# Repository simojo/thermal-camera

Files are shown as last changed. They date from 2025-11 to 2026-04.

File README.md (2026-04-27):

# Thermal camera based on Raspberry Pi Pico and MLX90640

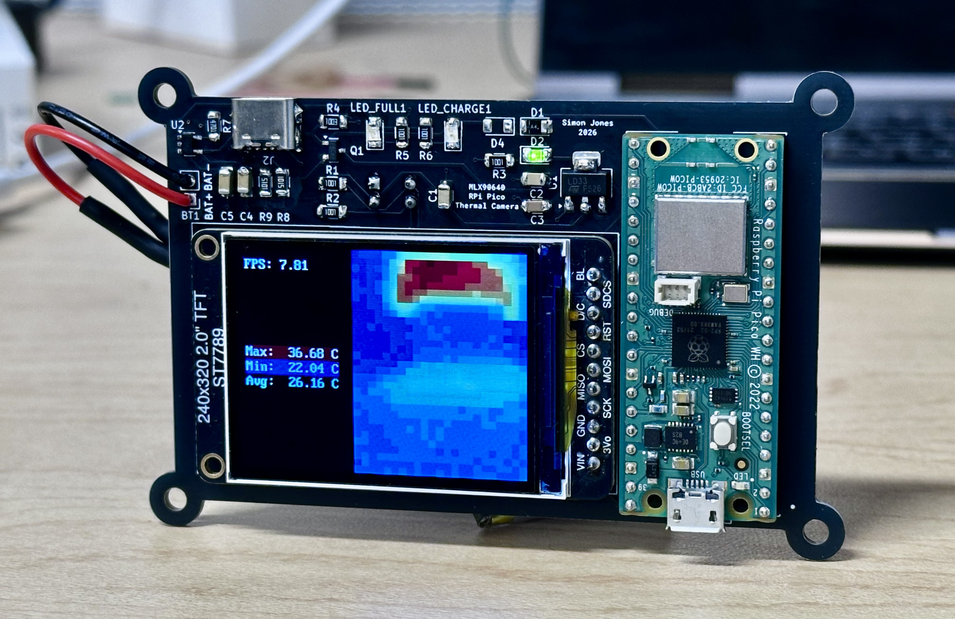
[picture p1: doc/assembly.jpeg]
Assembled Board


## Overview

This camera was a dream I've had for a while to use up some parts I had lying
around on my bench. I took an embedded system design course in Fall 2025 under
Linden McClure, and I used it as an opportunity to prototype a design using wire
wrapping. The code worked, and I could use it as a thermal camera, but in April
2026, I finally taped it out to a PCB which is conducive to an enclosure and
being more rugged. I wrote the library for displaying to the thin-film
transistor display manually as the key effort to the project.

## User features

* 7 FPS refresh rate
* Dynamic color mapping
* Real-time temperature readout (min/max)
* USB-C charging
* 3.7V Lithium polymer/ion battery

## Technical Features

* CMake based project
* KiCad based layout
* Supports charging over battery
* MCP73831 charger with charging/full indicators
* 3.3V logic and power

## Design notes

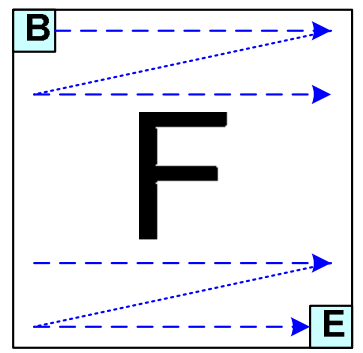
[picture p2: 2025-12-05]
st7789-orientation.png

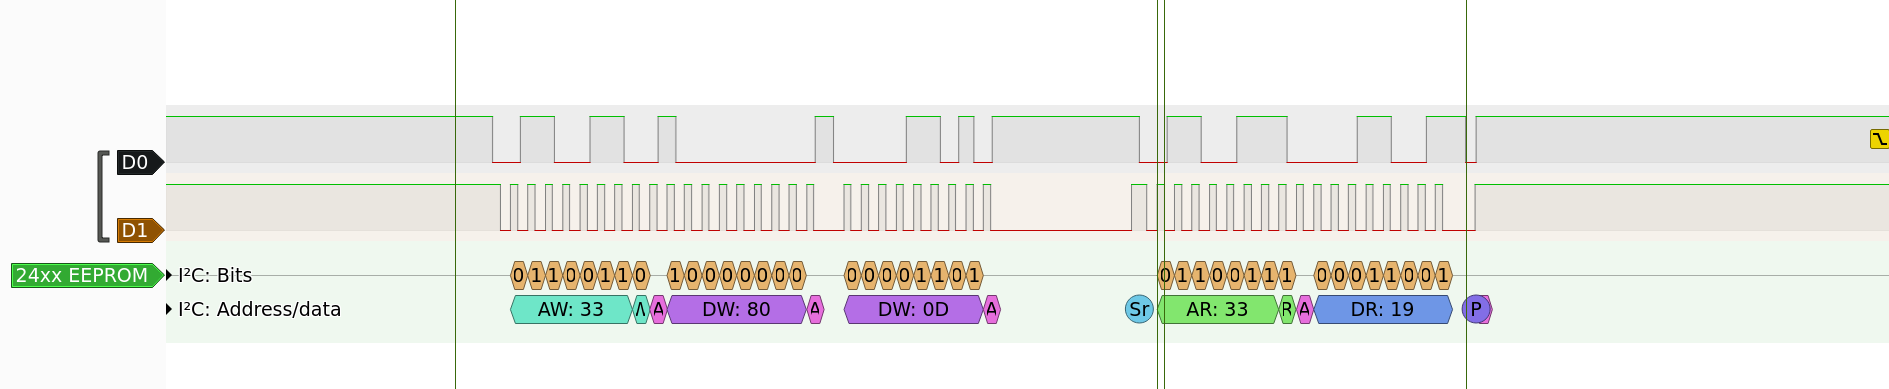
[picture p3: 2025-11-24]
first-logic-analyzer-reading.png

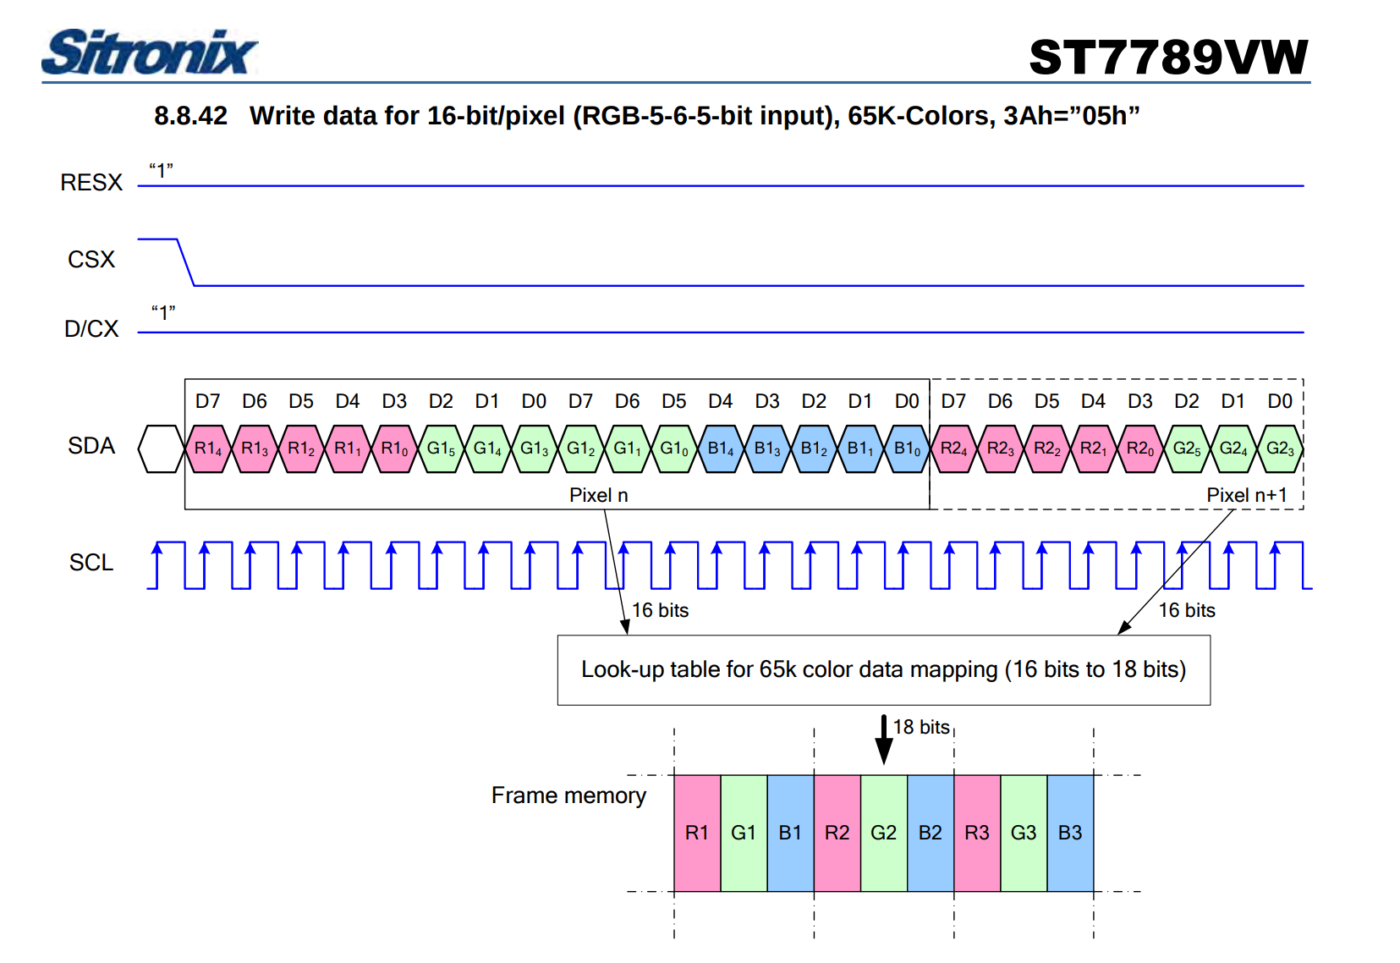
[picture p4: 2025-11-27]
rgb565-st7789.png

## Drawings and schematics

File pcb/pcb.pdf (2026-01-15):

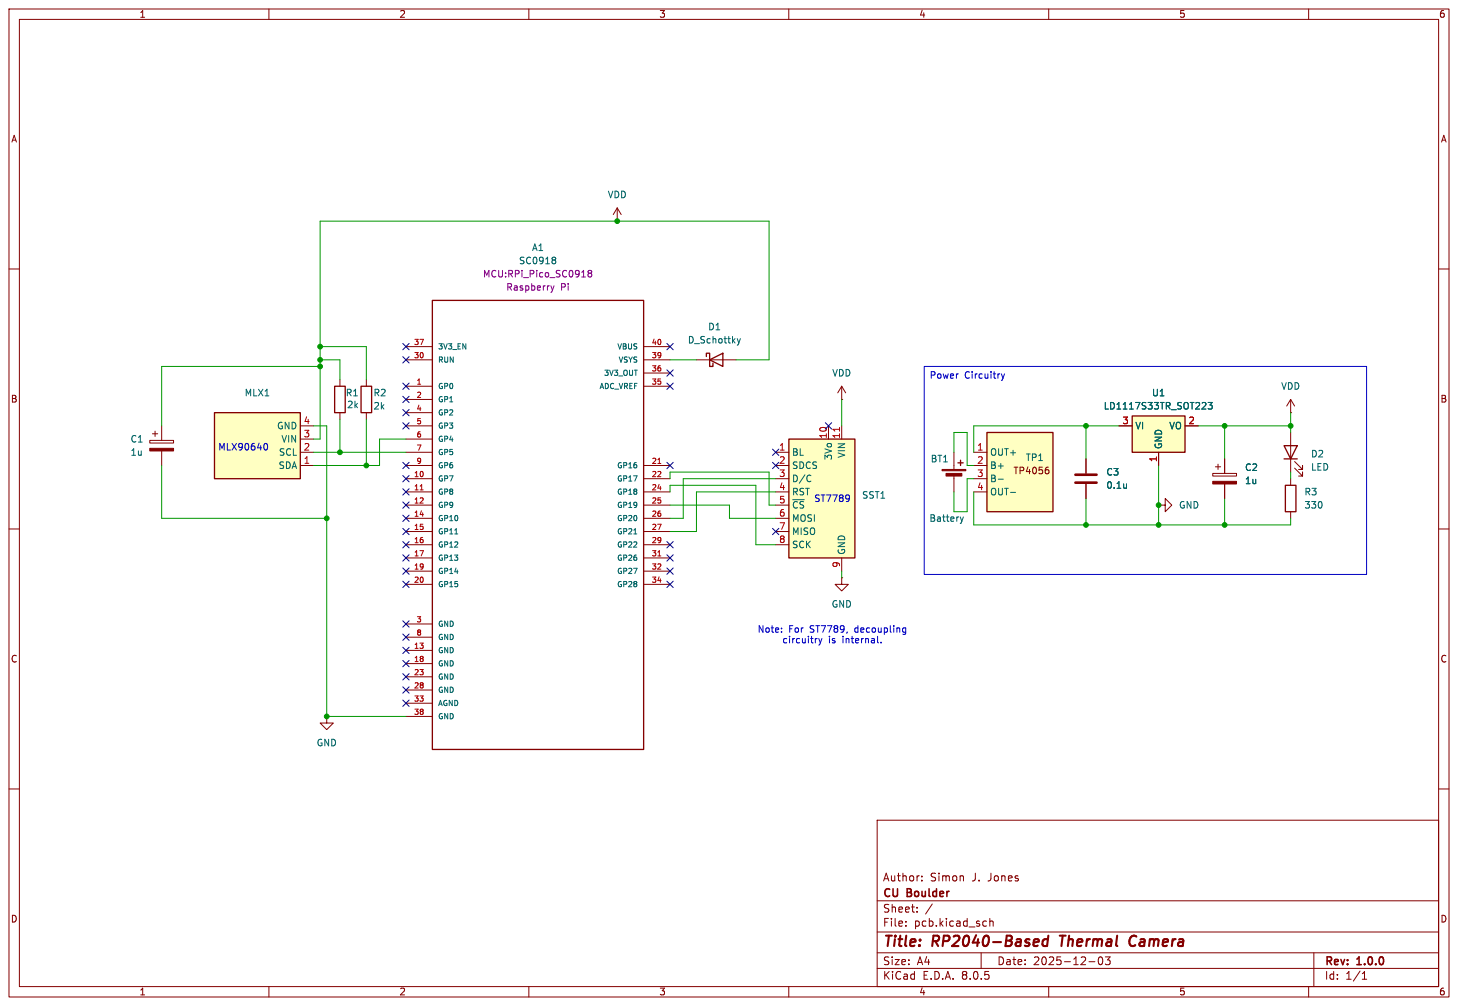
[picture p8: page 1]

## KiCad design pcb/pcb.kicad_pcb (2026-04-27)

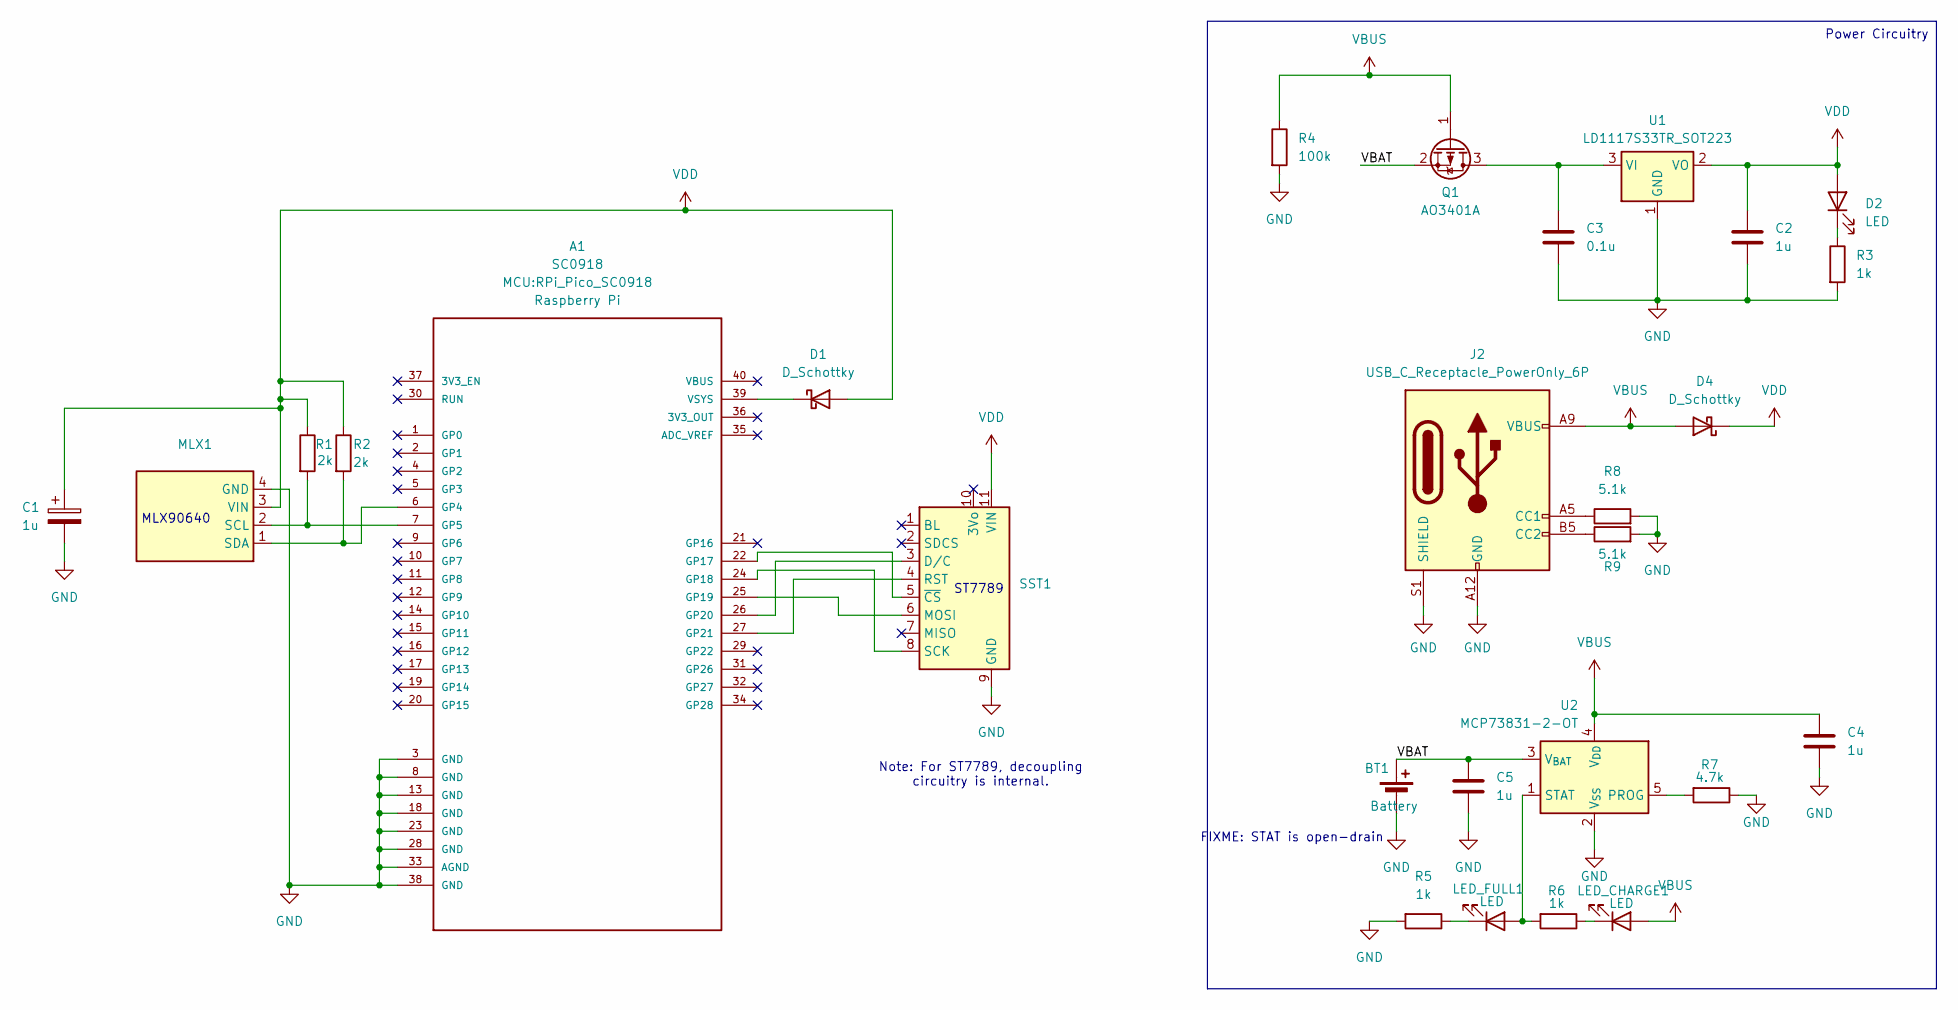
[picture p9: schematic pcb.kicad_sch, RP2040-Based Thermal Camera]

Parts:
A1: SC0918; RPi_Pico_SC0918; PARTREV 1.6
BT1: Battery; PinHeader_1x02_P2.54mm_Vertical
C1, C2, C4, C5: 1u; C_1206_3216Metric
C3: 0.1u; C_1206_3216Metric
D1, D4: D_Schottky; D_1206_3216Metric
D2: LED; LED_1206_3216Metric
J2: USB_C_Receptacle_PowerOnly_6P; USB_C_Receptacle_GCT_USB4125-xx-x-0190_6P_TopMnt_Horizontal
LED_CHARGE1: LED; LED_1206_3216Metric
LED_FULL1: LED; LED_1206_3216Metric
MLX1: MLX90640
Q1: AO3401A; SOT-23
R1, R2: 2k; R_1206_3216Metric
R3, R5, R6: 1k; R_1206_3216Metric
R4: 100k; R_1206_3216Metric
R7: 4.7k; R_1206_3216Metric
R8, R9: 5.1k; R_1206_3216Metric
SST1: Adafruit-ST7789
U1: LD1117S33TR_SOT223; SOT-223-3_TabPin2
U2: MCP73831-2-OT; SOT-23-5

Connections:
/VBAT: BT1.1 (+), C5.1, Q1.2 (S), U2.3 (V_{BAT})
GND: A1.3 (GND), A1.8 (GND), A1.13 (GND), A1.18 (GND), A1.23 (GND), A1.28 (GND), A1.33 (AGND), A1.38 (GND), BT1.2 (-), C1.2, C2.2, C3.2, C4.2, C5.2, J2.A12 (GND), J2.B12 (GND), J2.S1 (SHIELD), MLX1.4 (GND), R3.2, R4.2, R5.2, R7.1, R8.2, R9.2, SST1.9 (GND), U1.1 (GND), U2.2 (V_{SS})
unnamed: A1.6 (GP4), MLX1.1 (SDA), R2.2
unnamed: A1.7 (GP5), MLX1.2 (SCL), R1.2
unnamed: A1.22 (GP17), SST1.5 (~CS)
unnamed: A1.24 (GP18), SST1.8 (SCK)
unnamed: A1.25 (GP19), SST1.6 (MOSI)
unnamed: A1.26 (GP20), SST1.3 (D/C)
unnamed: A1.27 (GP21), SST1.4 (RST)
unnamed: A1.39 (VSYS), D1.1 (K)
unnamed: D2.1 (K), R3.1
unnamed: J2.A5 (CC1), R8.1
unnamed: J2.B5 (CC2), R9.1
unnamed: LED_CHARGE1.1 (K), R6.1
unnamed: LED_FULL1.2 (A), R6.2, U2.1 (STAT)
unnamed: LED_FULL1.1 (K), R5.1
unnamed: C3.1, Q1.3 (D), U1.3 (VI)
unnamed: R7.2, U2.5 (PROG)
VBUS: C4.1, D4.2 (A), J2.A9 (VBUS), J2.B9 (VBUS), LED_CHARGE1.2 (A), Q1.1 (G), R4.1, U2.4 (V_{DD})
VDD: C1.1, C2.1, D1.2 (A), D2.2 (A), D4.1 (K), MLX1.3 (VIN), R1.1, R2.1, SST1.11 (VIN), U1.2 (VO)

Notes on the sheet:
Power Circuitry
FIXME: STAT is open-drain
MLX90640
Note: For ST7789, decoupling circuitry is internal.
ST7789

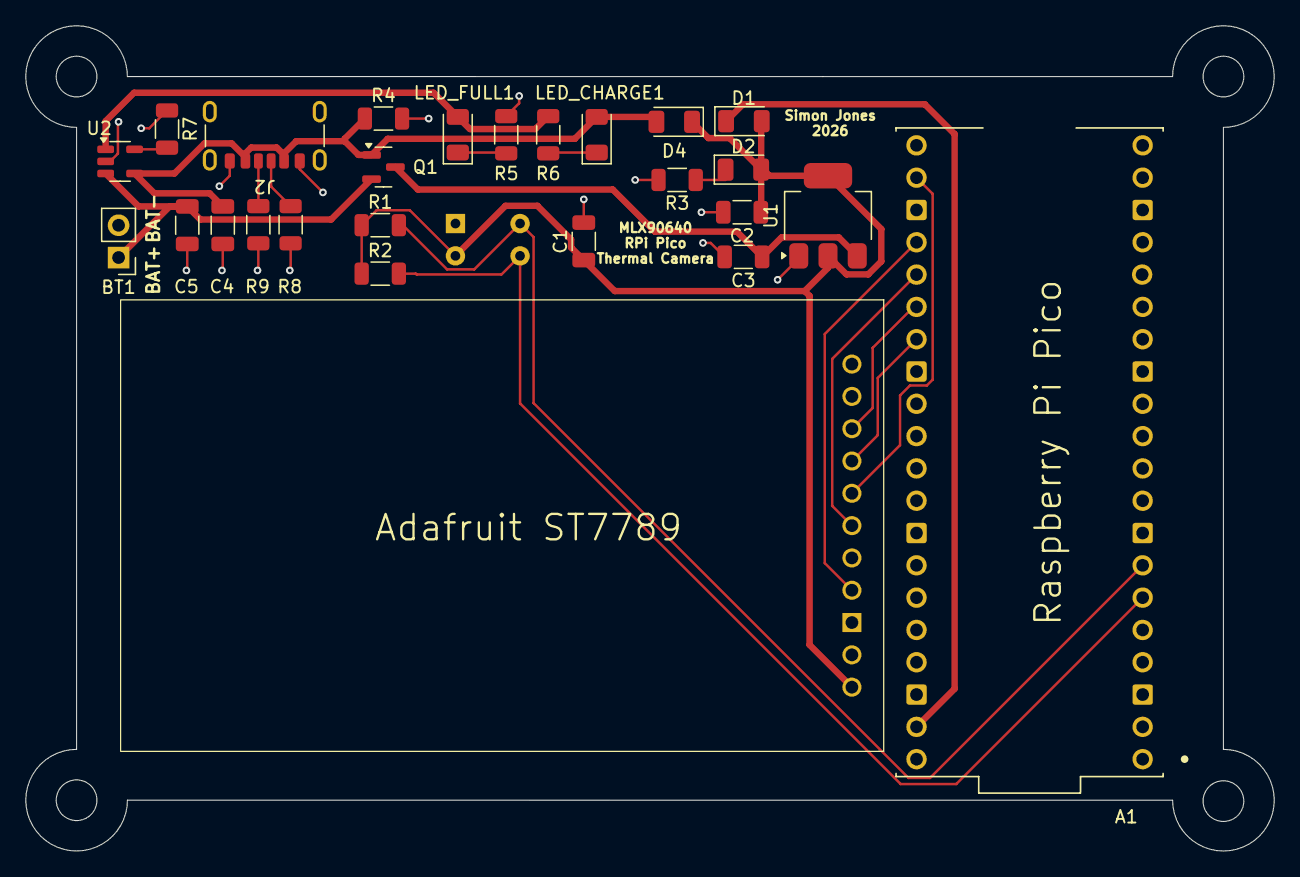
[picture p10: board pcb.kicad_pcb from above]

Board: 2 copper layers, 98.2 x 64.9 mm, 27 parts (1 on the bottom side), 20 nets.

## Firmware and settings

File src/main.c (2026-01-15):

/*
 * main.c
 *
 * @copyright Copyright (C) 2025 Simon J. Jones <github@simonjjones.com>
 * Licensed under the Apache License, Version 2.0.
 */

#include <pico/stdio.h>
#include <math.h>
#include <stdio.h>
#include "hardware/gpio.h"
#include "pico/stdlib.h"
#include "mlx90640/MLX90640_API.h"
#include "mlx90640/MLX90640_I2C_Driver.h"
#include "st7789.h"
#include "st7789_framebuf.h"
#include "pico/multicore.h"
#include "pico/mutex.h"

#define MLX90640_ADDR 0x33
#define INITIAL_DELAY_MS 6000

#define MLX90640_REFRESH_RATE_4HZ 0b011
#define MLX90640_REFRESH_RATE_8HZ 0b100
#define MLX90640_REFRESH_RATE_16HZ 0b101

static uint16_t eeData[MLX90640_EEPROM_DUMP_NUM];

paramsMLX90640 mlx90640;
static float frameTemperatureCore0[MLX90640_PIXEL_NUM];
static float frameTemperatureCore1[MLX90640_PIXEL_NUM];
static uint16_t frameData[MLX90640_PIXEL_NUM + 64 + 2];

mutex_t mutex;
volatile bool frameTemperatureChanged = false;

/*
 * core1_main
 *
 * @brief This core is for loading and sending the frame buffer.
 */
void core1_main() {
  // clear the st7789 display
  st7789_init();

  // display a loading animation while core0 starts up.
  uint32_t t0_ms = time_us_32() / 1000;
  uint32_t t1_ms = t0_ms;
  uint32_t loading_ani_t0_ms = t0_ms;
  const unsigned int loading_ani_tick_period_ms = 10;
  while (t1_ms - t0_ms < INITIAL_DELAY_MS) {
    t1_ms = time_us_32() / 1000;
    // each 200ms, tick the loading animation
    if (t1_ms - loading_ani_t0_ms > loading_ani_tick_period_ms) {
      st7789_loading_ani_tick();
      loading_ani_t0_ms = time_us_32() / 1000;
    }
  }
  // clear any remaining loading animations
  st7789_framebuf_fill_rect(0, 0, ST7789_LINE_SIZE-1, ST7789_COLUMN_SIZE-1, BLACK);

  while (1) {
    mutex_enter_blocking(&mutex);
    if (frameTemperatureChanged) {
      st7789_fill_32_24(frameTemperatureCore1);
      frameTemperatureChanged = false;
    }
    mutex_exit(&mutex);
  }
}

int main() {
  stdio_init_all();

  // initialize the mutex and launch core for handling st7789
  mutex_init(&mutex);
  multicore_launch_core1(core1_main);

  // add delay for the camera to start up
  sleep_ms(INITIAL_DELAY_MS);

  printf("[INFO] set refresh rate.\n");
  MLX90640_SetChessMode(MLX90640_ADDR);
  printf("[INFO] set chess mode.\n");
  MLX90640_SetSubPageRepeat(MLX90640_ADDR, 0);
  printf("[INFO] set subpage repeat.\n");

  if (MLX90640_DumpEE(MLX90640_ADDR, eeData) != 0) {
    printf("[ERROR] DumpEE returned error.\n");
  }
  printf("[INFO] dumpEE.\n");
  // set the refresh rate to be 8Hz
  MLX90640_SetRefreshRate(MLX90640_ADDR, MLX90640_REFRESH_RATE_8HZ);

  // after reading the EEPROM, we can read much faster.
  MLX90640_I2CFreqSet(1000 * 1000);

  if (MLX90640_ExtractParameters(eeData, &mlx90640) != 0) {
    printf("[ERROR] ExtractParameters returned error.\n");
  }
  printf("[INFO] extractparameters.\n");
  MLX90640_I2CWrite(MLX90640_ADDR, MLX90640_STATUS_REG, MLX90640_INIT_STATUS_VALUE);

  uint16_t frameTemperatureColorsRGB565[MLX90640_PIXEL_NUM];

  while (1) {

    int subpage = 0;
    subpage = MLX90640_GetFrameData(MLX90640_ADDR, frameData);
    // 0, 1 are valid subpge return values. anything else implies error
    if (subpage == 0 || subpage == 1) {
      float eTa = MLX90640_GetTa(frameData, &mlx90640) - 8;
      float emissivity = 0.95;


      MLX90640_CalculateTo(frameData, &mlx90640, emissivity, eTa, frameTemperatureCore0);

      // NOTE: leaving this out because we do have bad pixels and this breaks it
      // MLX90640_BadPixelsCorrection((&mlx90640)->brokenPixels, frameTemperatureCore0, 1, &mlx90640);
      // MLX90640_BadPixelsCorrection((&mlx90640)->outlierPixels, frameTemperatureCore0, 1, &mlx90640);

      // signal to the core1 that we're ready to draw the next frame
      mutex_enter_blocking(&mutex);

      frameTemperatureChanged = true;
      for (int i = 0; i < MLX90640_PIXEL_NUM; i++) {
        frameTemperatureCore1[i] = frameTemperatureCore0[i];
      }

      mutex_exit(&mutex);

    } else {
      printf("[ERROR] MLX90640 failed while getting frame data (%d).\n", subpage);
    }
  }
}

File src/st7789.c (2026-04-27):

/*
 * st7789.c
 *
 * @copyright Copyright (C) 2025 Simon J. Jones <github@simonjjones.com>
 * Licensed under the Apache License, Version 2.0.
 */

#include <stdio.h>
#include <stdlib.h>
#include <stdbool.h>
#include "hardware/spi.h"
#include "pico/stdlib.h"
#include "hardware/gpio.h"
#include <malloc.h>
#include "st7789.h"
#include "fonts.h"
#include "st7789_framebuf.h"
#include <math.h>
#include "mlx90640/MLX90640_API.h"

#define RES_PIN 21
#define DC_PIN 20

volatile bool st7789_is_init = false;

#define N_HEATMAP_COLORS 20
/*
 * define ten colors that create the heat map
 */
const uint16_t heatmap_color_rgb565[] = {
    RGB565(0, 0, 128),
    RGB565(0, 0, 191),
    RGB565(0, 64, 255),
    RGB565(0, 128, 255),
    RGB565(0, 191, 255),
    RGB565(0, 255, 255),
    RGB565(0, 255, 191),
    RGB565(0, 255, 128),
    RGB565(0, 255, 64),
    RGB565(0, 255, 0),
    RGB565(64, 255, 0),
    RGB565(128, 255, 0),
    RGB565(191, 255, 0),
    RGB565(255, 255, 0),
    RGB565(255, 191, 0),
    RGB565(255, 128, 0),
    RGB565(255, 64, 0),
    RGB565(255, 0, 0),
    RGB565(191, 0, 0),
    RGB565(128, 0, 0)
};



void st7789_write_data_byte(uint8_t b);
void st7789_write_command(uint8_t cmd);

void st7789_init(void) {
  gpio_set_function(PICO_DEFAULT_SPI_TX_PIN, GPIO_FUNC_SPI);
  gpio_set_function(PICO_DEFAULT_SPI_RX_PIN, GPIO_FUNC_SPI);
  gpio_set_function(PICO_DEFAULT_SPI_SCK_PIN, GPIO_FUNC_SPI);

  gpio_init(PICO_DEFAULT_SPI_CSN_PIN);
  gpio_init(DC_PIN);
  gpio_init(RES_PIN);
  gpio_set_dir(PICO_DEFAULT_SPI_CSN_PIN, GPIO_OUT);
  gpio_set_dir(DC_PIN, GPIO_OUT);
  gpio_set_dir(RES_PIN, GPIO_OUT);
  spi_init(spi_default, (uint)20e6);

  gpio_put(PICO_DEFAULT_SPI_CSN_PIN, 1);
  gpio_put(DC_PIN, 1);

  gpio_put(RES_PIN, 0);
  sleep_ms(20);
  gpio_put(RES_PIN, 1);
  sleep_ms(150);

  st7789_is_init = true;

  // heavily inspired from adafruit's source code for arduino with the st7789
  // https://github.com/adafruit/Adafruit-ST7735-Library/blob/master/Adafruit_ST7789.cpp#L50-L77
  st7789_write_command(ST7789_CMD_SWRESET);
  sleep_ms(150);
  st7789_write_command(ST7789_CMD_SLPOUT);
  sleep_ms(10);
  st7789_write_command(ST7789_CMD_COLMOD);
  st7789_write_data_byte(0x55); // 65k RGB interface, 16b per pixel (datasheet: p 224)
  sleep_ms(10);
  st7789_write_command(ST7789_CMD_MADCTL);
  st7789_write_data_byte(0x60); // MV, MX, MY = 1 1 0 (rotate 90 clockwise)
  st7789_write_command(ST7789_CMD_INVON); // adafruit claims this helps to avoid startup issues
  sleep_ms(10);
  st7789_write_command(ST7789_CMD_NORON); // normal display mode on
  sleep_ms(10);
  st7789_write_command(ST7789_CMD_DISPON); // display on
  sleep_ms(10);
}

void st7789_dc_data(void) {
  gpio_put(DC_PIN, 1);
}

void st7789_dc_command(void) {
  gpio_put(DC_PIN, 0);
}

void st7789_select(void) {
  // chip select is active low
  gpio_put(PICO_DEFAULT_SPI_CSN_PIN, 0);
}

void st7789_unselect(void) {
  // chip select is active low (make high)
  gpio_put(PICO_DEFAULT_SPI_CSN_PIN, 1);
}

void st7789_write_data(uint8_t *buf, uint len) {
  if (!st7789_is_init) {
    st7789_init();
  }
  st7789_dc_data();
  st7789_select();
  spi_write_blocking(spi_default, buf, len);
  st7789_unselect();
}

void st7789_write_data_words(uint16_t *buf, uint len) {
  size_t newlen = len * 2;

  // shift word-sized buffer around to be big-endian
  for (int i = 0; i < len; i++) {
    uint16_t temp = buf[i];
    buf[i] = (temp >> 8) | (temp << 8); // HSB -> LSB order
  }
  // cast buffer as uint8_t* after we shift its endianness
  st7789_write_data((uint8_t*)buf, newlen);

  // unshift word-sized buffer around to be little-endian
  // so that we don't leave the data mutated.
  for (int i = 0; i < len; i++) {
    uint16_t temp = buf[i];
    buf[i] = (temp >> 8) | (temp << 8);
  }
}

void st7789_write_data_byte(uint8_t b) {
  st7789_write_data(&b, 1);
}


void st7789_write_command(uint8_t cmd) {
  if (!st7789_is_init) {
    st7789_init();
  }
  st7789_dc_command();
  st7789_select();
  spi_write_blocking(spi_default, &cmd, 1);
  st7789_unselect();
}

void st7789_set_window(uint x0, uint y0, uint x1, uint y1) {
  uint8_t data[4];

  // column address set for x0, x1
  st7789_write_command(ST7789_CMD_CASET);
  data[0] = (x0 >> 8) & 0xFF;
  data[1] = (x0 >> 0) & 0xFF;
  data[2] = (x1 >> 8) & 0xFF;
  data[3] = (x1 >> 0) & 0xFF;
  st7789_write_data(data, 4);

  // row address set for y0, y1
  st7789_write_command(ST7789_CMD_RASET);
  data[0] = (y0 >> 8) & 0xFF;
  data[1] = (y0 >> 0) & 0xFF;
  data[2] = (y1 >> 8) & 0xFF;
  data[3] = (y1 >> 0) & 0xFF;
  st7789_write_data(data, 4);
}

void st7789_draw_pixel(uint x, uint y, uint16_t color) {
  st7789_set_window(x, y, x, y);
  st7789_write_command(ST7789_CMD_RAMWR);
  uint8_t data[2];

  data[0] = (color >> 8) & 0xFF; // HSB
  data[1] = (color >> 0) & 0xFF; // LSB

  st7789_write_data(data, 2);
}

/*
 * st7789_draw_line
 *
 * @brief Draw a line on using Bresenham's line algorithm.
 */
void st7789_draw_line(uint x0, uint y0, uint x1, uint y1, uint16_t color) {
  // use Bresenham's line algorithm (source: https://en.wikipedia.org/wiki/Bresenham%27s_line_algorithm)

  int dx = abs((int)x1 - (int)x0);
  // direction of x
  int dirx = x0 < x1 ? 1 : -1;
  int dy = -abs((int)y1 - (int)y0);
  // direction of x
  int diry = y0 < y1 ? 1 : -1;
  int e = dx + dy;

  // modify x0,y0 directly because we passed by value
  while (1) {
    st7789_draw_pixel(x0, y0, color);

    if (x0 == x1 && y0 == y1) {
      break;
    }

    int e2 = 2 * e;
    if (e2 >= dy) {
      e += dy;
      x0 += dirx;
    }
    if (e2 <= dx) {
      e += dx;
      y0 += diry;
    }
  }
}

void st7789_fill_rect(uint x0, uint y0, uint x1, uint y1, uint16_t color) {
  st7789_set_window(x0, y0, x1, y1);
  st7789_write_command(ST7789_CMD_RAMWR);
  uint32_t rect_size_words = (x1 - x0 + 1) * (y1 - y0 + 1);
  uint32_t rect_size_bytes = rect_size_words * sizeof(uint16_t);
  // each pixel has size uint16_t
  uint8_t *buf = malloc(rect_size_bytes);
  if (!buf) {
    printf("[ERROR] st7789_fill_rect: unable to malloc.\n");
    return;
  }
  // fill the entire buffer with the same color
  for (int i = 0; i < rect_size_words; i++) {
    buf[2 * i]     = (color >> 8) & 0xFF; // HSB
    buf[2 * i + 1] = (color >> 0) & 0xFF; // LSB
  }
  st7789_write_data(buf, rect_size_bytes);
  free(buf);
}

static uint8_t st7789_loading_ani_state = 0;
#define ST7789_LOADING_ANI_N_STATES 7
#define ST7789_LOADING_ANI_N_LINES 6
#define ST7789_LOADING_ANI_N_CHARS 13
static const char st7789_loading_ani_words[ST7789_LOADING_ANI_N_STATES][ST7789_LOADING_ANI_N_CHARS+1] = {
  "   Loading   ",
  "  <Loading>  ",
  " <<Loading>> ",
  "<<<Loading>>>",
  " <<Loading>> ",
  "  <Loading>  ",
  "   Loading   ",
};
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

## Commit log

2025-10-16 feat: pico-sdk
2025-10-16 Basically init the entire project with semi-working thermal camera code.
2025-11-25 feat: change version of pico-sdk
2025-11-25 feat: putting pico sdk to new version
2025-11-26 feat: adding bit banged i2c; mlx90640 still fails
    [main.c, st7789.c]
2025-11-26 feat: changing to pico (not w) fixes voltage level problems, but then I changed how we pushed out data over i2c_read, and things broke again. Things worked exactly once then broke.... word vomit yes,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
    [main.c, st7789.c]
2025-11-27 feat: spi screen works with american flag configuration in correct orientation.
    [main.c, st7789.c]
2025-11-28 feat: (untested) add functions for buffering mlx data, line drawing, writing words to spi
2025-11-29 feat: adding kicad schem, i2c works. No code change, but verifying that i2c works after fixing faulty mlx90640 circuitry (thanks adafruit...)
    [pcb.kicad_pcb, pcb.kicad_sch]
2025-11-29 fix: i2c implementation working with in-house i2c. going to rely on that moving forward. pixels are still outliers, but its okay
2025-11-30 feat: i2c works, reading temperatures works but flaots are invalid. Only one chess pattern shows too.
2025-11-30 feat: working frame buffering
2025-11-30 feat: nice heatmap
2025-12-01 feat: (untested) no more frame area diffing, allowing rotations of mlx90640, drawing circles, removing scanner.h, externing thefont
2025-12-01 doc: tweaking comments and error message
    [main.c]
2025-12-03 feat: flawless loading screen, flawless temperature calc, flawless fps
2025-12-03 feat: (not working) unable to add a silly wifi feature. will revert
    [main.c]
2025-12-03 Revert "feat: (not working) unable to add a silly wifi feature. will revert"
    This reverts commit c03468f307befe720b908f2ef61763585e224b50.
    [main.c]
2025-12-05 feat: kicad files
    [pcb.kicad_pcb, pcb.kicad_sch]
2026-01-15 feat: dt rather than fps
    [pcb.kicad_pcb, pcb.kicad_sch]
2026-04-27 feat: pcb for first tape out
2026-04-27 feat: switch screen orientation markers to account for camera loc on pcb
2026-04-27 chore: changes to schematic
    [pcb.kicad_pcb, pcb.kicad_sch]
